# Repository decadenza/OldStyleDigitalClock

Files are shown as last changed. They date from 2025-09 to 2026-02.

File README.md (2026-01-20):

# Old Style Digital Clock
A simple, fully functional digital clock without microcontrollers.

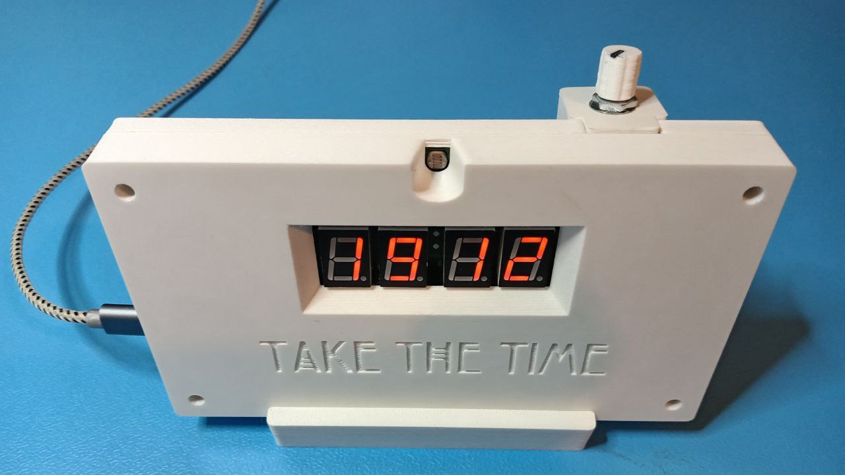
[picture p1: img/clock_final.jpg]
The old style digital clock


## Features
- HH:MM 24-hour format.
- Based on common and readily available components like counters and logic gates.
- This clock uses a Pierce oscillator circuit (quartz crystal), so it will keep the time much more accurately than a NE555 or similar timers.
- Powered by USB C female port.
- 2 x USB A ports for charging other devices (as dedicated charging ports - DCPs).
- Dimmable LEDs and self-adjusting brightness.

### LED brightness control
LEDs may result too faint in daylight and too bright at night. Therefore brightness is controlled by pulse-width modulation (PWM) and a potentiometer to adjust the duty cycle.
Furthermore, a light-dependent resistor (LDR) is introduced to automatically reduce the duty cycle at night.

The signal measured at one active LED segment is a square wave of a frequency > 30 Hz so that human eye cannot notice the flickering:

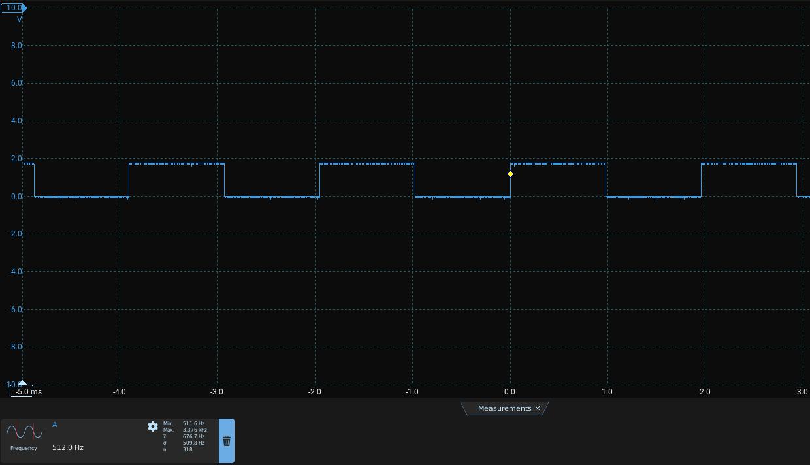
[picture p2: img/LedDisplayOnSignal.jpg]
LED signal


You may notice flickering if you use a camera to look at the clock. If this is a concern, you may reduce the C13 capacitor value to increase the frequency to the desired level. Full details in the schematics.

## PCB printing
A standard 2-layer PCB is used. You may generate the necessary Gerber and drill files using KiCad according to the specs of your supplier.

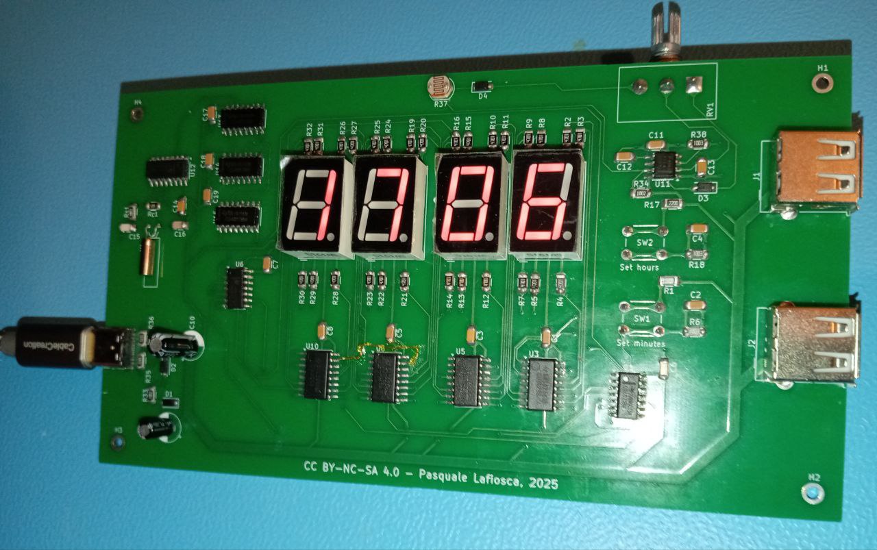
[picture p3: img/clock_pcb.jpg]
The old style digital clock


## 3D models
The clock may be completed by printing the case. See [3D printed parts](3DPrintedParts) folder. 

## License
This project is licensed under the **CC BY-NC-SA 4.0** license.  
© 2025 Pasquale Lafiosca

For more details, see the [LICENSE](LICENSE) file.

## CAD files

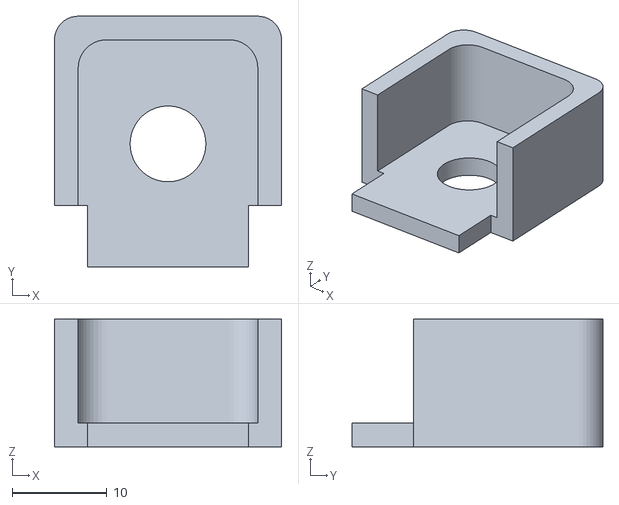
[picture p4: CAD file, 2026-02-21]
3DPrintedParts/potentiometer_shield.stl
24.0 x 26.5 x 13.5

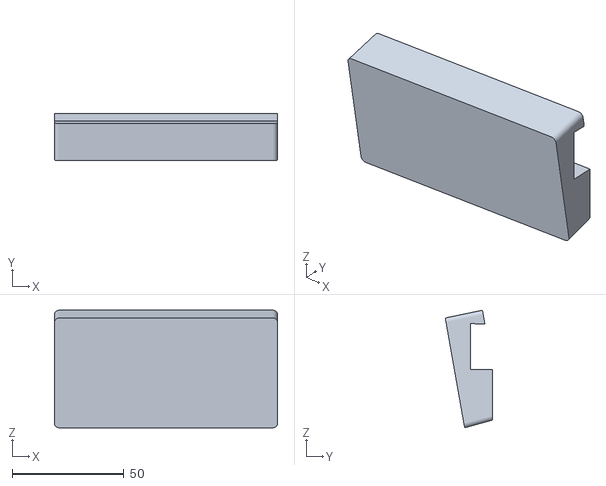
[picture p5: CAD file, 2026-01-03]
3DPrintedParts/support.stl
100.0 x 21.3 x 52.7

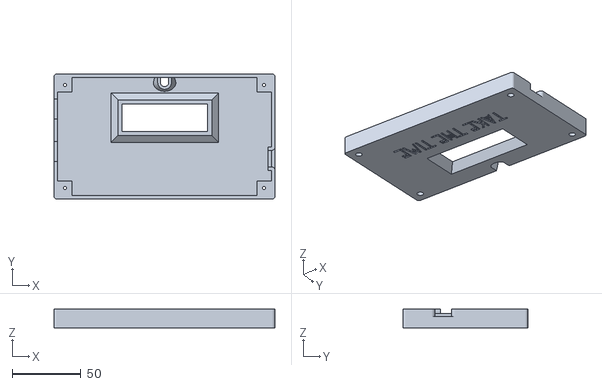
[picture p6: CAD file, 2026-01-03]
3DPrintedParts/front.stl
161.0 x 91.0 x 13.8

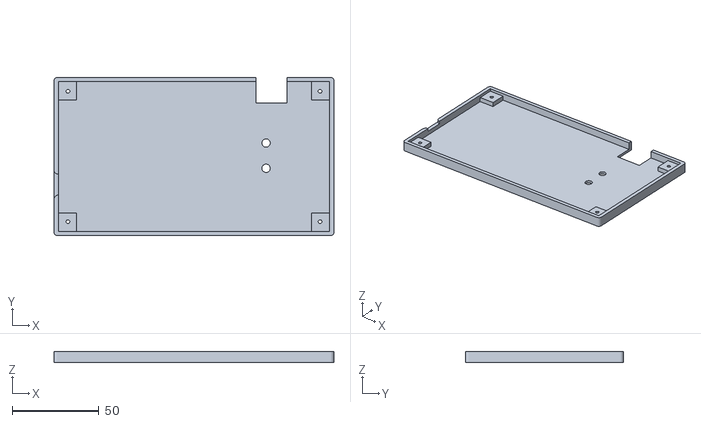
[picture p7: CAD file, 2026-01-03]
3DPrintedParts/back.stl
161.0 x 91.0 x 6.40

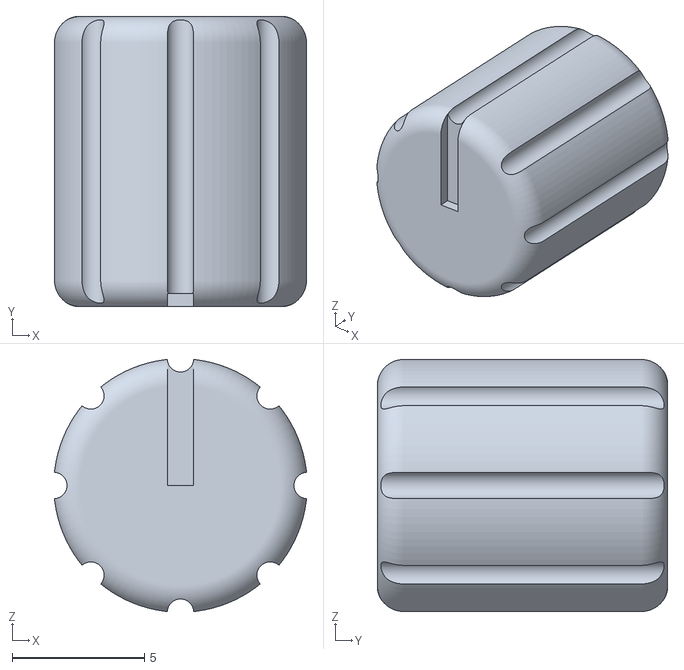
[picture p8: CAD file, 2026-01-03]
3DPrintedParts/potentiometer_cap.stl
9.54 x 11.0 x 9.54

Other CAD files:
3DPrintedParts/enclosure.blend

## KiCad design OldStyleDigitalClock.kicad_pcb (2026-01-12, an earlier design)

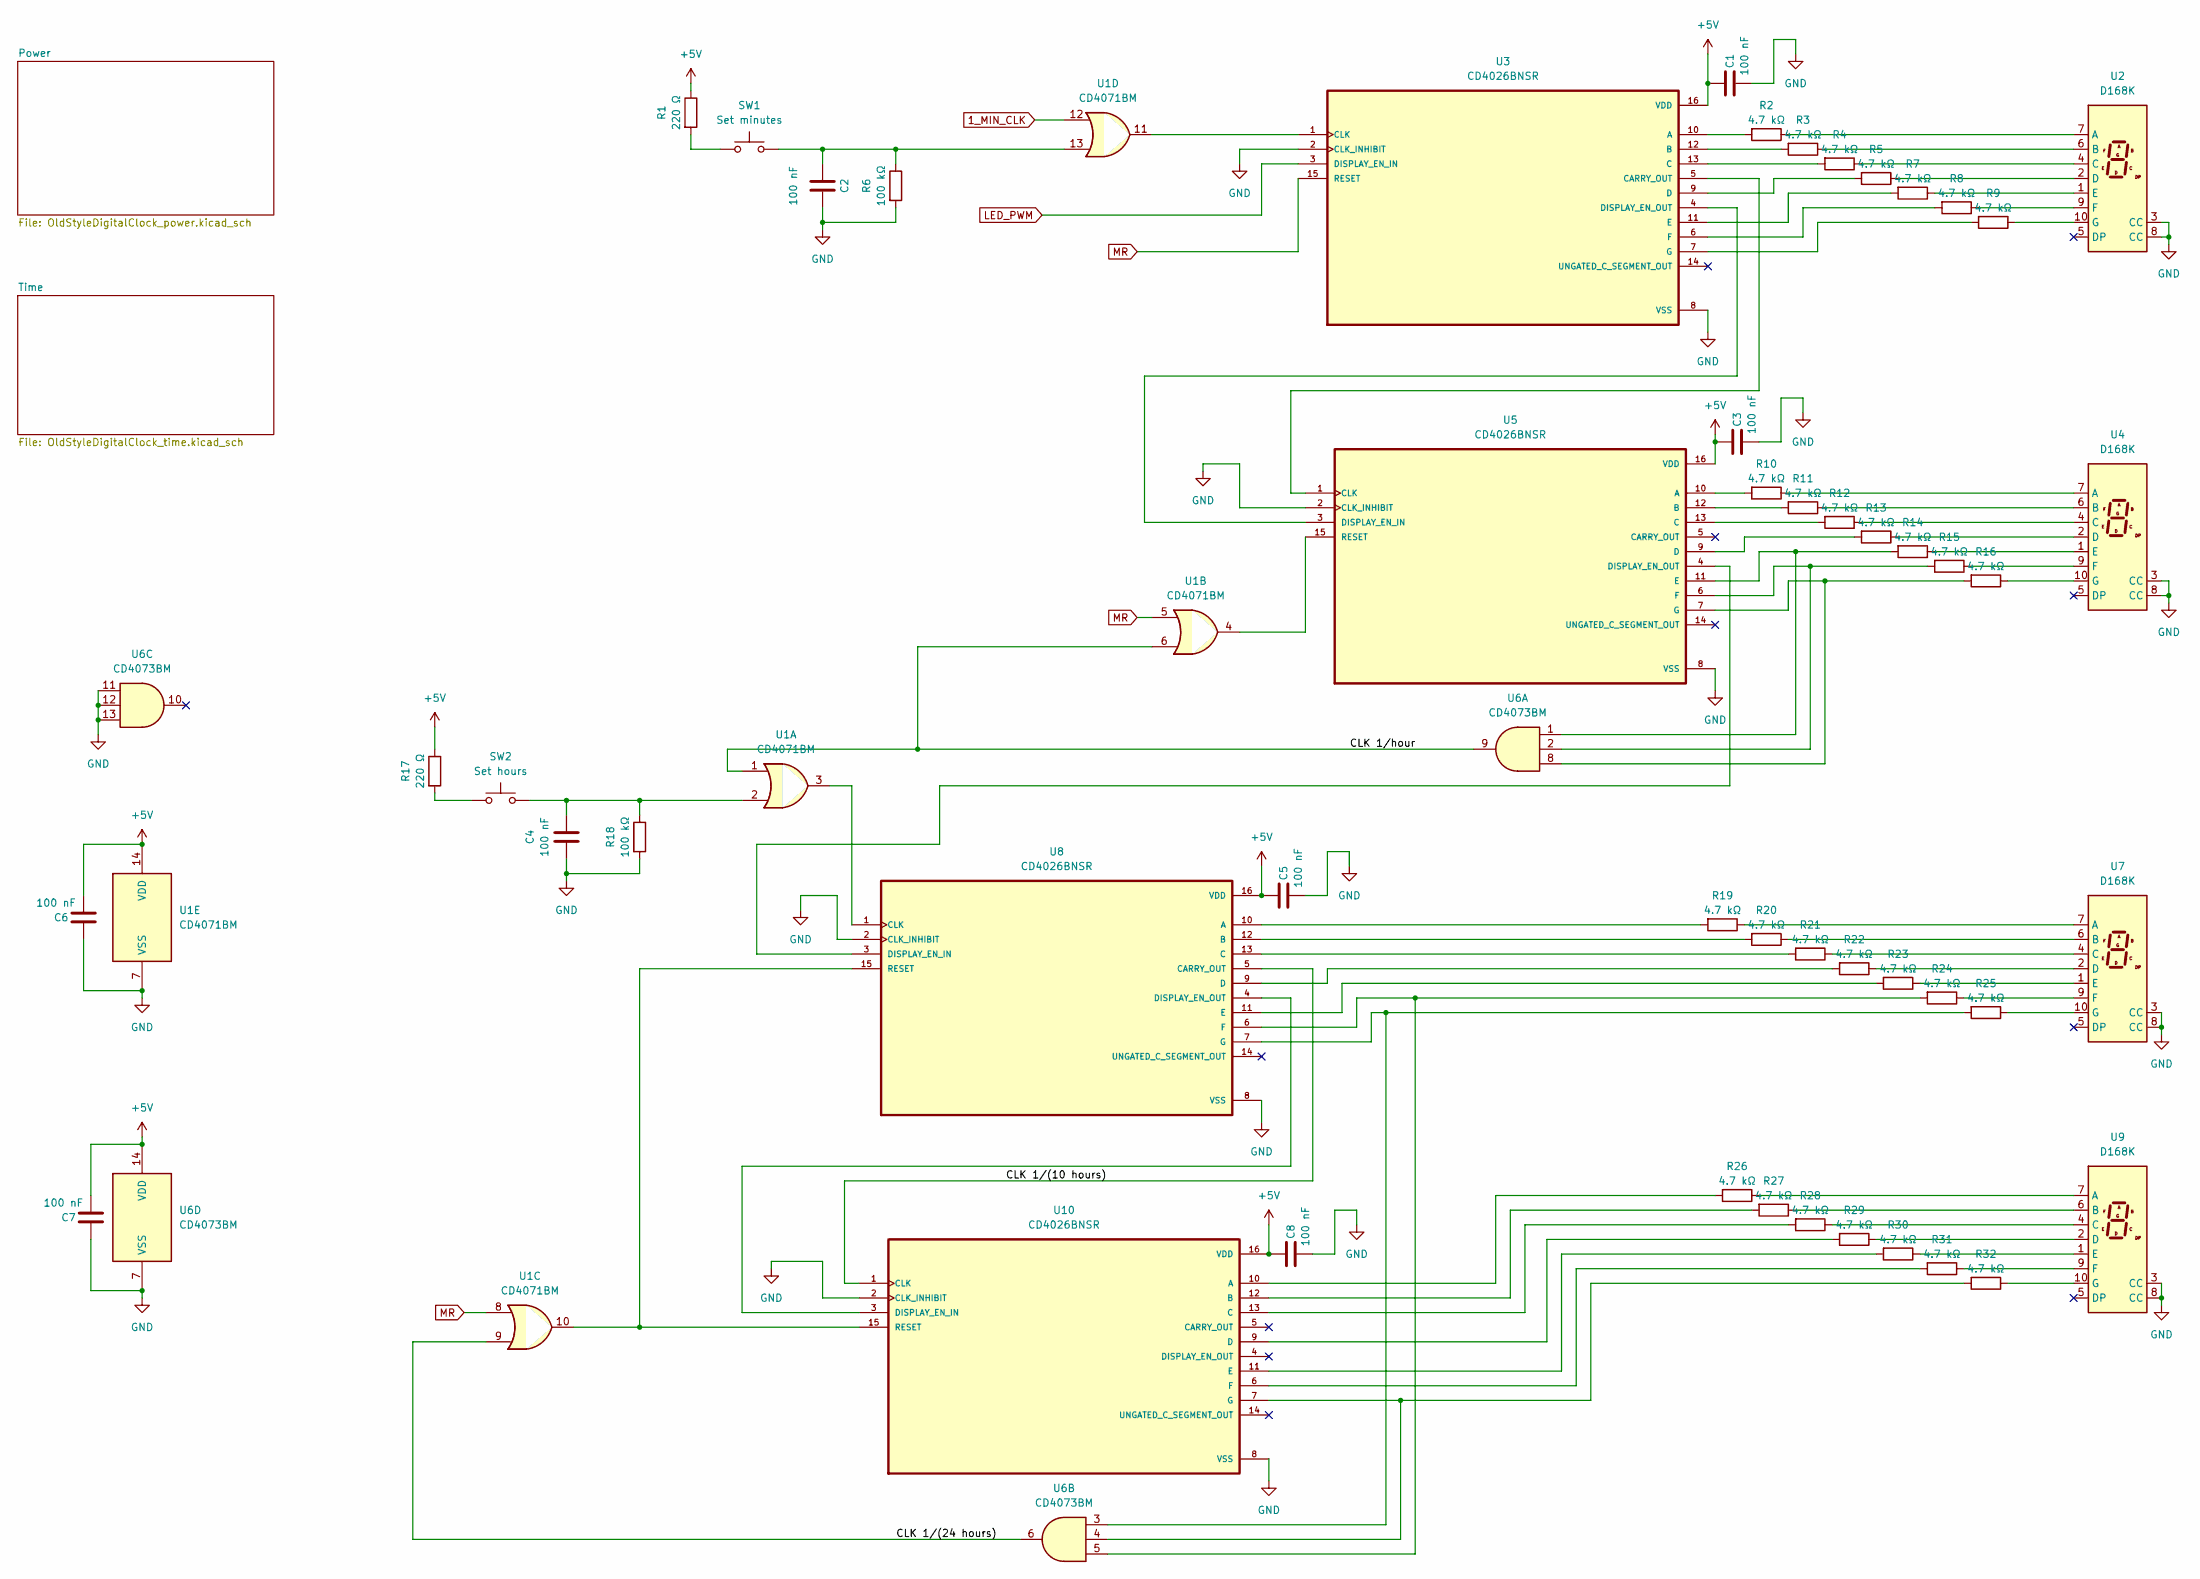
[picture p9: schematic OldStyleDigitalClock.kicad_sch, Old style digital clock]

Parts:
C1, C2, C3, C4, C5, C6, C7, C8: 100 nF; C_1206_3216Metric
R1, R17: 220 Ω; R_1206_3216Metric
R2, R3, R4, R5, R7, R8, R9, R10, R11, R12, R13, R14, R15, R16, R19, R20, R21, R22, R23, R24, R25, R26, R27, R28, R29, R30, R31, R32: 4.7 kΩ; R_1206_3216Metric
R6, R18: 100 kΩ; R_1206_3216Metric
SW1: Set minutes; SW_PUSH_6mm
SW2: Set hours; SW_PUSH_6mm
U1: CD4071BM; SOIC-14_3.9x8.7mm_P1.27mm
U2, U4, U7, U9: D168K; D1X8K
U3, U5, U8, U10: CD4026BNSR; SOIC-16W_5.3x10.2mm_P1.27mm
U6: CD4073BM; SOIC-14_3.9x8.7mm_P1.27mm

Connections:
1_MIN_CLK: U1.12; also elsewhere on the board
+5V: C1.1, C3.1, C5.1, C6.2, C7.2, C8.1, R1.1, R17.1, U1.14 (VDD), U3.16 (VDD), U5.16 (VDD), U6.14 (VDD), U8.16 (VDD), U10.16 (VDD); also elsewhere on the board
/CLK 1/(10 hours): U8.5 (CARRY_OUT), U10.1 (CLK)
/CLK 1/(24 hours): U1.9, U6.6
/CLK 1/hour: U1.1, U1.6, U6.9
GND: C1.2, C2.1, C3.2, C4.1, C5.2, C6.1, C7.1, C8.2, R6.2, R18.2, U1.7 (VSS), U2.3 (CC), U2.8 (CC), U3.2 (CLK_INHIBIT), U3.8 (VSS), U4.3 (CC), U4.8 (CC), U5.2 (CLK_INHIBIT), U5.8 (VSS), U6.7 (VSS), U6.11, U6.12, U6.13, U7.3 (CC), U7.8 (CC), U8.2 (CLK_INHIBIT), U8.8 (VSS), U9.3 (CC), U9.8 (CC), U10.2 (CLK_INHIBIT), U10.8 (VSS); also elsewhere on the board
LED_PWM: U3.3 (DISPLAY_EN_IN); also elsewhere on the board
MR: U1.5, U1.8, U3.15 (RESET); also elsewhere on the board
unnamed: C2.2, R6.1, SW1.2, U1.13
unnamed: C4.2, R18.1, SW2.2, U1.2
unnamed: R1.2, SW1.1
unnamed: R17.2, SW2.1
unnamed: R2.1, U2.7 (A)
unnamed: R3.1, U2.6 (B)
unnamed: R4.1, U2.4 (C)
unnamed: R5.1, U2.2 (D)
unnamed: R7.1, U2.1 (E)
unnamed: R8.1, U2.9 (F)
unnamed: R9.1, U2.10 (G)
unnamed: R2.2, U3.10 (A)
unnamed: R3.2, U3.12 (B)
unnamed: R4.2, U3.13 (C)
unnamed: U3.5 (CARRY_OUT), U5.1 (CLK)
unnamed: U1.11, U3.1 (CLK)
unnamed: R5.2, U3.9 (D)
unnamed: U3.4 (DISPLAY_EN_OUT), U5.3 (DISPLAY_EN_IN)
unnamed: R7.2, U3.11 (E)
unnamed: R8.2, U3.6 (F)
unnamed: R9.2, U3.7 (G)
unnamed: R10.1, U4.7 (A)
unnamed: R11.1, U4.6 (B)
unnamed: R12.1, U4.4 (C)
unnamed: R13.1, U4.2 (D)
unnamed: R14.1, U4.1 (E)
unnamed: R15.1, U4.9 (F)
unnamed: R16.1, U4.10 (G)
unnamed: R10.2, U5.10 (A)
unnamed: R11.2, U5.12 (B)
unnamed: R12.2, U5.13 (C)
unnamed: R13.2, U5.9 (D)
unnamed: U5.4 (DISPLAY_EN_OUT), U8.3 (DISPLAY_EN_IN)
unnamed: R14.2, U5.11 (E), U6.1
unnamed: R15.2, U5.6 (F), U6.2
unnamed: R16.2, U5.7 (G), U6.8
unnamed: U1.4, U5.15 (RESET)
unnamed: R19.1, U7.7 (A)
unnamed: R20.1, U7.6 (B)
unnamed: R21.1, U7.4 (C)
unnamed: R22.1, U7.2 (D)
unnamed: R23.1, U7.1 (E)
unnamed: R24.1, U7.9 (F)
unnamed: R25.1, U7.10 (G)
unnamed: R19.2, U8.10 (A)
unnamed: R20.2, U8.12 (B)
unnamed: R21.2, U8.13 (C)
unnamed: U1.3, U8.1 (CLK)
unnamed: R22.2, U8.9 (D)
unnamed: R23.2, U8.11 (E)
unnamed: R24.2, U6.5, U8.6 (F)
unnamed: R25.2, U6.3, U8.7 (G)
unnamed: R26.1, U9.7 (A)
unnamed: R27.1, U9.6 (B)
unnamed: R28.1, U9.4 (C)
unnamed: R29.1, U9.2 (D)
unnamed: R30.1, U9.1 (E)
unnamed: R31.1, U9.9 (F)
unnamed: R32.1, U9.10 (G)
unnamed: R26.2, U10.10 (A)
unnamed: R27.2, U10.12 (B)
unnamed: R28.2, U10.13 (C)
unnamed: R29.2, U10.9 (D)
unnamed: U8.4 (DISPLAY_EN_OUT), U10.3 (DISPLAY_EN_IN)
unnamed: R30.2, U10.11 (E)
unnamed: R31.2, U10.6 (F)
unnamed: R32.2, U6.4, U10.7 (G)
unnamed: U1.10, U8.15 (RESET), U10.15 (RESET)

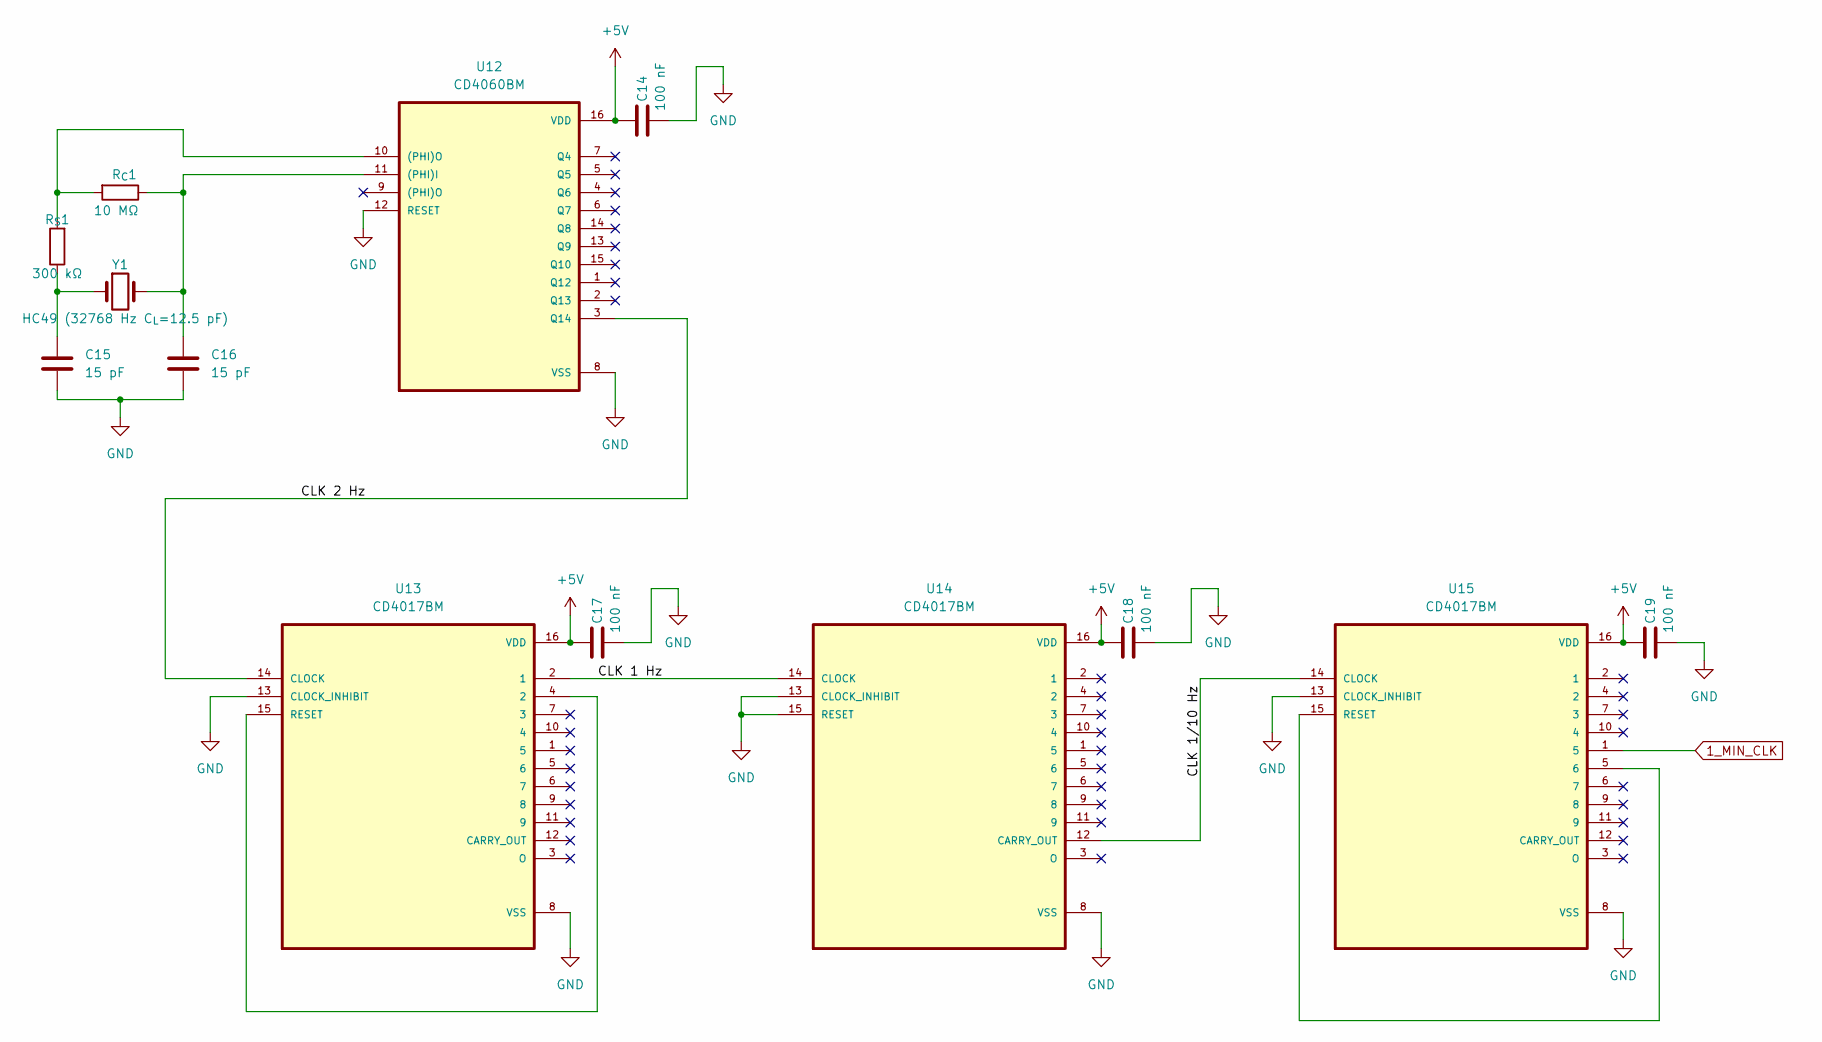
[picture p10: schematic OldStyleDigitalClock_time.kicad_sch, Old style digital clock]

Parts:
C14, C17, C18, C19: 100 nF; C_1206_3216Metric
C15, C16: 15 pF; C_1206_3216Metric
R_{C}1: 10 MΩ; R_1206_3216Metric
R_{S}1: 300 kΩ; R_1206_3216Metric
U12: CD4060BM; SOIC-16_3.9x9.9mm_P1.27mm
U13, U14, U15: CD4017BM; SOIC-16_3.9x9.9mm_P1.27mm
Y1: HC49 (32768 Hz C_{L}=12.5 pF); Crystal_AT310_D3.0mm_L10.0mm_Horizontal

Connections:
1_MIN_CLK: U15.1 (5); also elsewhere on the board
+5V: C14.1, C17.1, C18.1, C19.1, U12.16 (VDD), U13.16 (VDD), U14.16 (VDD), U15.16 (VDD); also elsewhere on the board
/Time/CLK 1 Hz: U13.2 (1), U14.14 (CLOCK)
/Time/CLK 1/10 Hz: U14.12 (CARRY_OUT), U15.14 (CLOCK)
/Time/CLK 2 Hz: U12.3 (Q14), U13.14 (CLOCK)
GND: C14.2, C15.2, C16.2, C17.2, C18.2, C19.2, U12.8 (VSS), U12.12 (RESET), U13.8 (VSS), U13.13 (CLOCK_INHIBIT), U14.8 (VSS), U14.13 (CLOCK_INHIBIT), U14.15 (RESET), U15.8 (VSS), U15.13 (CLOCK_INHIBIT); also elsewhere on the board
unnamed: C15.1, R_{S}1.1, Y1.1
unnamed: R_{C}1.2, R_{S}1.2, U12.10 ((PHI)O)
unnamed: C16.1, R_{C}1.1, U12.11 ((PHI)I), Y1.2
unnamed: U13.4 (2), U13.15 (RESET)
unnamed: U15.5 (6), U15.15 (RESET)

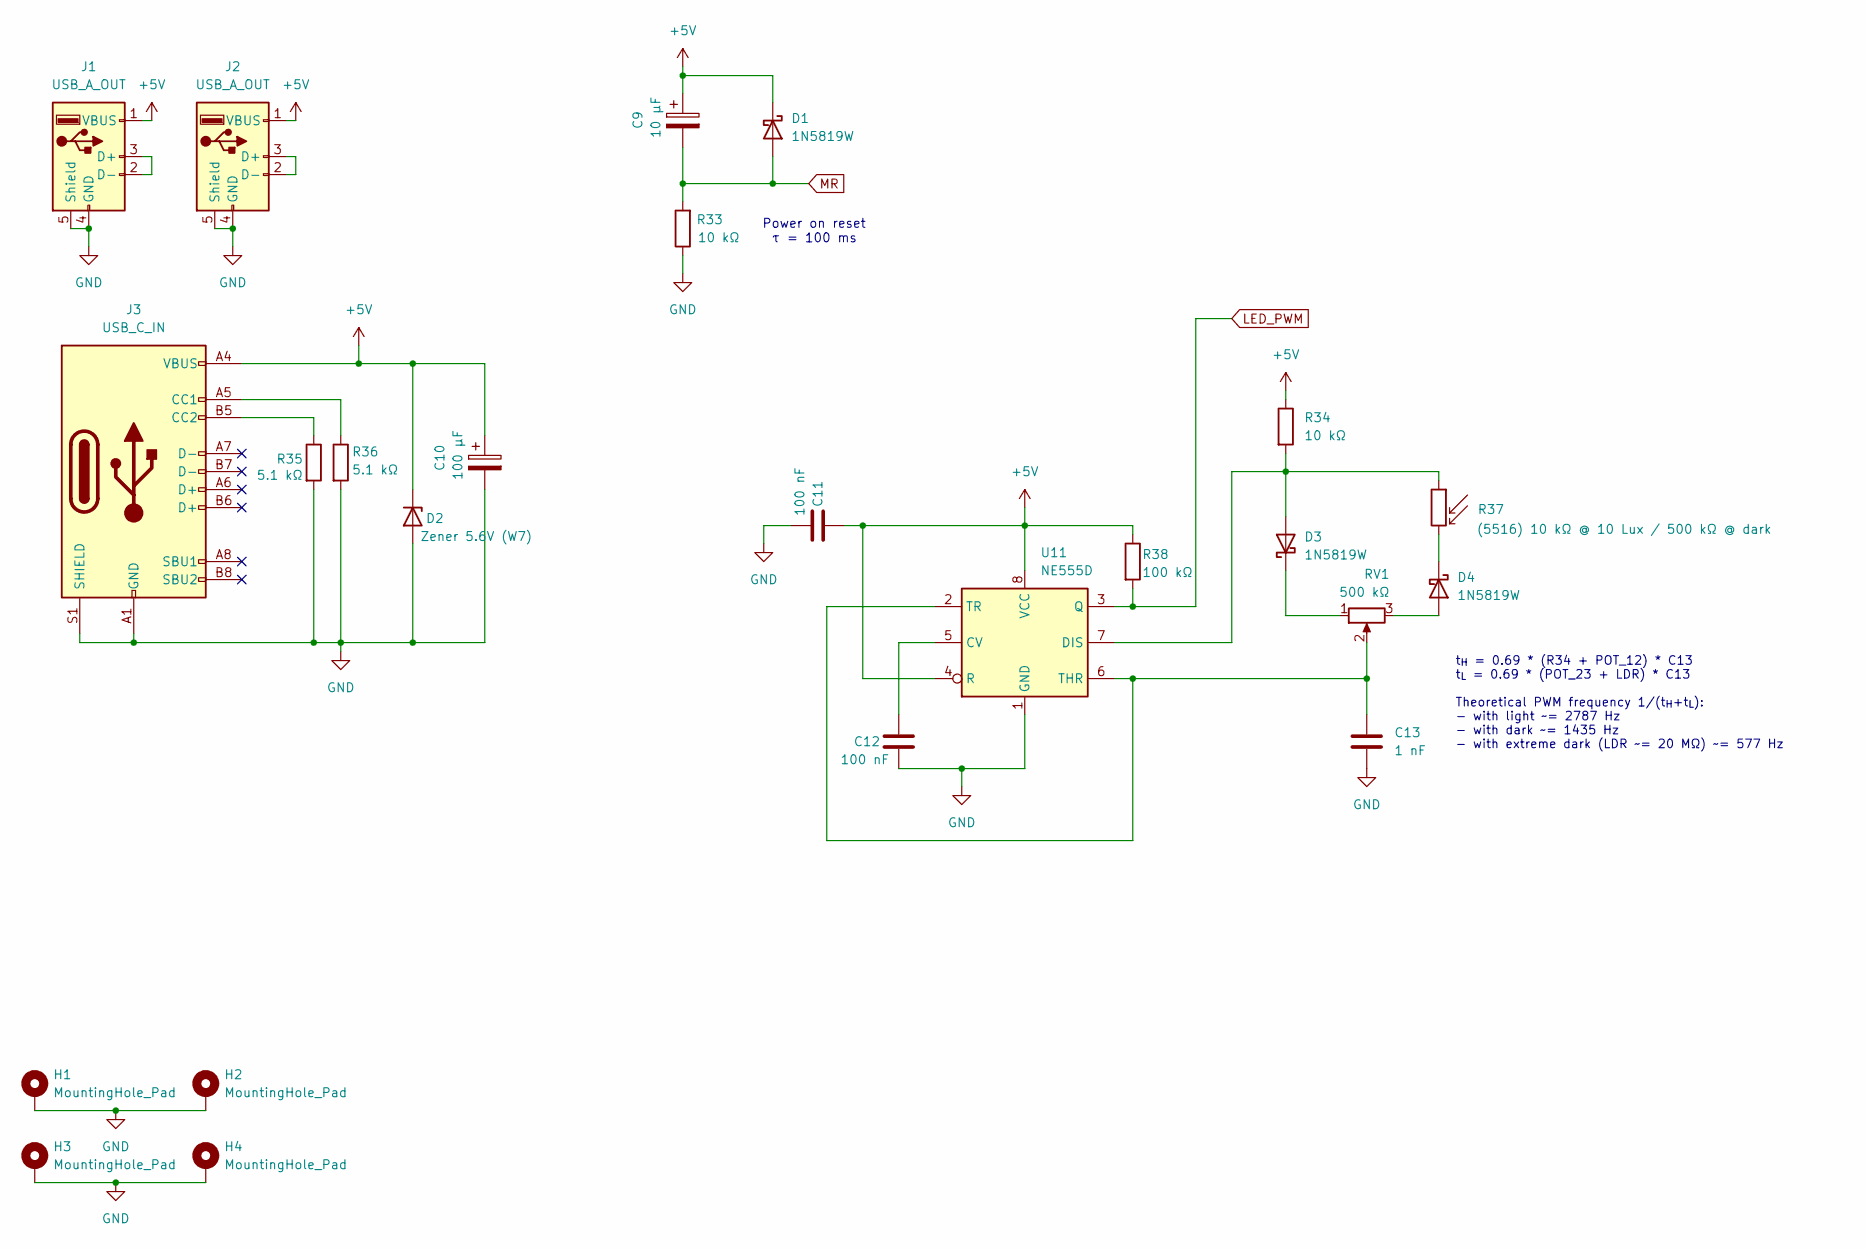
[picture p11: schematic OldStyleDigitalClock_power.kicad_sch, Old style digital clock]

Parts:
C9: 10 µF; CP_Radial_D6.3mm_P2.50mm
C10: 100 µF; CP_Radial_D6.3mm_P2.50mm
C11, C12: 100 nF; C_1206_3216Metric
C13: 1 nF; C_1206_3216Metric
D1, D3, D4: 1N5819W; D_SOD-123
D2: Zener 5.6V (W7); D_SOD-123
H1, H2, H3, H4: MountingHole_Pad; MountingHole_2.2mm_M2_DIN965_Pad
J1, J2: USB_A_OUT; USB_A_Molex_67643_Horizontal
J3: USB_C_IN; USB_C_Receptacle_XKB_U262-16XN-4BVC11
R33, R34: 10 kΩ; R_1206_3216Metric
R35, R36: 5.1 kΩ; R_1206_3216Metric
R37: (5516) 10 kΩ @ 10 Lux / 500 kΩ @ dark; R_LDR_5.1x4.3mm_P3.4mm_Vertical
R38: 100 kΩ; R_1206_3216Metric
RV1: 500 kΩ; Potentiometer_Alps_RK163_Single_Horizontal
U11: NE555D; SOIC-8_3.9x4.9mm_P1.27mm

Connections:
+5V: C9.1, C10.1, C11.1, D1.1 (K), D2.1 (K), J1.1 (VBUS), J2.1 (VBUS), J3.A4 (VBUS), J3.A9 (VBUS), J3.B4 (VBUS), J3.B9 (VBUS), R34.1, R38.1, U11.4 (R), U11.8 (VCC); also elsewhere on the board
GND: C10.2, C11.2, C12.2, C13.2, D2.2 (A), H1.1, H2.1, H3.1, H4.1, J1.4 (GND), J1.5 (Shield), J2.4 (GND), J2.5 (Shield), J3.A1 (GND), J3.A12 (GND), J3.B1 (GND), J3.B12 (GND), J3.S1 (SHIELD), R33.1, R35.2, R36.2, U11.1 (GND); also elsewhere on the board
LED_PWM: R38.2, U11.3 (Q); also elsewhere on the board
MR: C9.2, D1.2 (A), R33.2; also elsewhere on the board
unnamed: D3.2 (A), R34.2, R37.1, U11.7 (DIS)
unnamed: D3.1 (K), RV1.1
unnamed: D4.2 (A), RV1.3
unnamed: D4.1 (K), R37.2
unnamed: J1.2 (D-), J1.3 (D+)
unnamed: J2.2 (D-), J2.3 (D+)
unnamed: J3.A5 (CC1), R36.1
unnamed: J3.B5 (CC2), R35.1
unnamed: C12.1, U11.5 (CV)
unnamed: C13.1, RV1.2, U11.2 (TR), U11.6 (THR)

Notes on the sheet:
Power on reset τ = 100 ms
t_{H} = 0.69 * (R34 + POT_12) * C13 t_{L} = 0.69 * (POT_23 + LDR) * C13 Theoretical PWM frequency 1/(t_{H}+t_{L}): - with light ~= 2787 Hz - with dark ~= 1435 Hz - with extreme dark (LDR ~= 20 MΩ) ~= 577 Hz

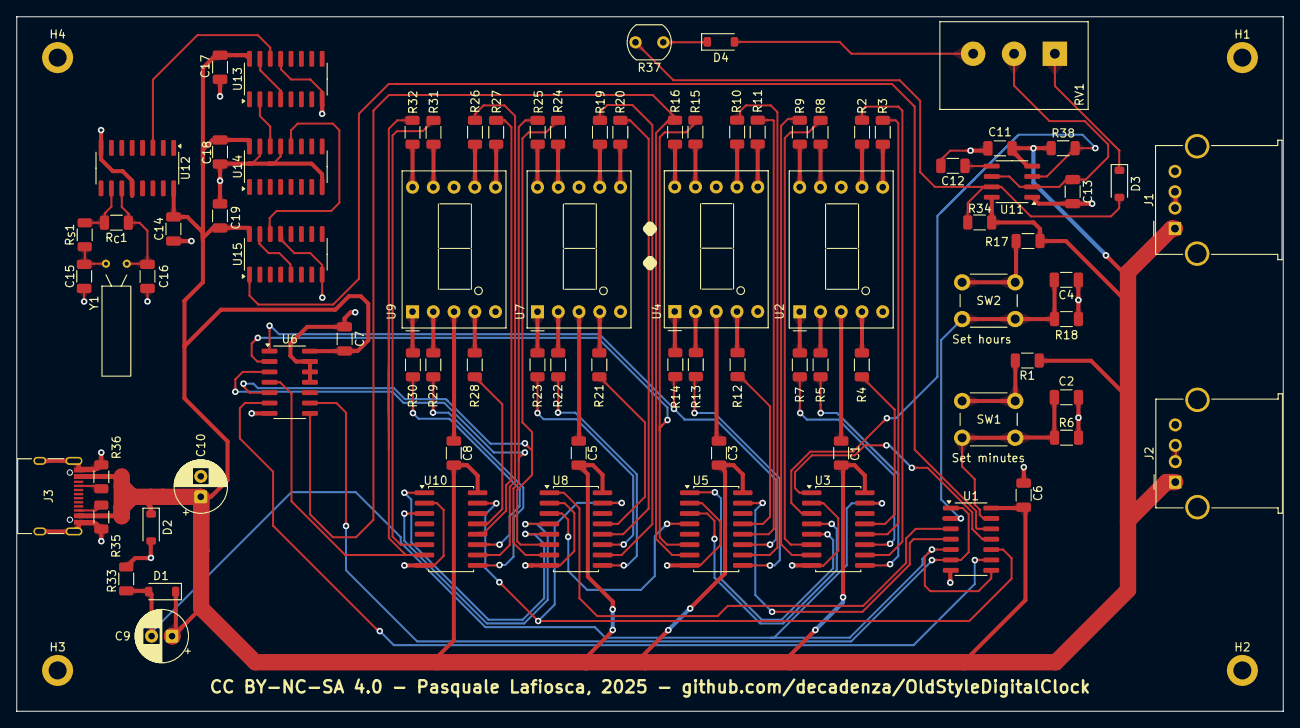
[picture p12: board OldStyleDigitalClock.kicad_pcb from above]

Board: 2 copper layers, 155.0 x 85.0 mm, 89 parts (0 on the bottom side), 94 nets.

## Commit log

2025-05-18 Uploaded project files
    [OldStyleDigitalClock.csv, OldStyleDigitalClock.kicad_pcb, OldStyleDigitalClock.kicad_sch]
2025-05-18 Added 3D printed stand and solar panel support
    [Solar panel support.stl, StandFlat.stl]
2025-05-18 Corrected 3D parts, added Blender file
    [OldStyleDigitalClockSupport.blend, Solar panel support.stl, Stand.stl]
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2025-05-31 Using 5 V solar cell instead of 4 V, as more appropriate for indoor situations
    [OldStyleDigitalClock.kicad_pcb, OldStyleDigitalClock.kicad_sch]
2025-08-17 Added different vertical and horizontal supports
    [OldStyleDigitalClockSupport.blend, Solar panel mount (horizontal).stl, Solar panel mount (vertical with support).stl]
2025-09-29 Using 512 Hz clock signal to rapidly turn on and off the LEDs via the CD4026 display enable pin, both saving 50% power and hopefully improving the battery charging. The LED attenuation is negligible.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
    [OldStyleDigitalClock.kicad_pcb, OldStyleDigitalClock.kicad_sch]
2025-09-30 Corrected LED display enable signal and decreased to 64 Hz to reduce capacitance and save power without any flickering visible
    [OldStyleDigitalClock.kicad_pcb, OldStyleDigitalClock.kicad_sch]
2025-10-11 Removed batteries and added USB connectors. One USB C for power in, two usb A power outlets. Pre-routing.
    [OldStyleDigitalClock.kicad_pcb, OldStyleDigitalClock.kicad_sch]
2025-10-12 Introducing PWM for dimmable LEDs
    [OldStyleDigitalClock.kicad_pcb, OldStyleDigitalClock.kicad_sch, OldStyleDigitalClock_main.kicad_sch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]
2025-10-13 Using standard astable multivibrator for LED dimming
    [OldStyleDigitalClock.kicad_sch, OldStyleDigitalClock_main.kicad_sch, OldStyleDigitalClock_power.kicad_sch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]
2025-10-13 Added photoresistor for automatic brightness adjustment
    [OldStyleDigitalClock_power.kicad_sch]
2025-10-16 Minor change to avoid issue with hours not changing
    [OldStyleDigitalClock.kicad_pcb, OldStyleDigitalClock.kicad_sch]
2025-10-17 Using OR gates instead of diodes. Changed POT for 555
    [OldStyleDigitalClock.kicad_sch, OldStyleDigitalClock_power.kicad_sch]
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2025-10-20 New PWM and POT configuration
    [OldStyleDigitalClock_power.kicad_sch]
2025-10-20 Added pull up on NA555 output. Minor changes.
    [OldStyleDigitalClock_power.kicad_sch]
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2025-10-20 Partial commit: Moved to SMD footprints
    [OldStyleDigitalClock.kicad_sch, OldStyleDigitalClock_power.kicad_sch, OldStyleDigitalClock_time.kicad_sch]
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2025-10-21 Constant frequency PWM with fixed LDR value
    [OldStyleDigitalClock_power.kicad_sch]
2025-10-21 Fixed typo
    [OldStyleDigitalClock_power.kicad_sch]
2025-10-22 Assigned footprints: first draft
    [OldStyleDigitalClock.kicad_pcb, OldStyleDigitalClock.kicad_sch, OldStyleDigitalClock_power.kicad_sch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]
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2025-10-28 Cleaning up for new layout
    [OldStyleDigitalClock.kicad_pcb]
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2025-11-02 Fixed issue in MR circuit. More tracks.
    [OldStyleDigitalClock.kicad_pcb, OldStyleDigitalClock_power.kicad_sch]
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2025-11-06 Tracks, first draft completed prior to design review
    [OldStyleDigitalClock.kicad_pcb, OldStyleDigitalClock_power.kicad_sch]
2025-11-06 connected mounting holes to GND
    [OldStyleDigitalClock.kicad_pcb, OldStyleDigitalClock_power.kicad_sch]
2025-11-06 Checked DRC, all ok except USB C clearances
    [OldStyleDigitalClock.kicad_pcb]
2025-11-07 Reduced board size, RDC passing except for USB C clearance.
    [OldStyleDigitalClock.kicad_pcb]
2025-11-07 Minor adjustments, moved oscillator away from mounting hole, improved some tracks.
    [OldStyleDigitalClock.kicad_pcb]
2025-11-08 Moved USB receptacles, minor changes. Marked no connect pins.
    [OldStyleDigitalClock.csv, OldStyleDigitalClock.kicad_pcb, OldStyleDigitalClock.kicad_sch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]
2025-11-08 Reviewed LED limiting resistors to stay within specs
    [OldStyleDigitalClock.kicad_pcb, OldStyleDigitalClock.kicad_sch, OldStyleDigitalClock_power.kicad_sch]
2025-11-09 Redesigned USB C input in a more compact way.
    [OldStyleDigitalClock.kicad_pcb, OldStyleDigitalClock_power.kicad_sch]
2025-11-13 Checked all IC against database and updated exact value and footprints
    [OldStyleDigitalClock.kicad_pcb, OldStyleDigitalClock.kicad_sch, OldStyleDigitalClock_time.kicad_sch]
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2025-11-25 fixed MR circuit (again)
    [OldStyleDigitalClock.kicad_pcb, OldStyleDigitalClock.kicad_sch, OldStyleDigitalClock_power.kicad_sch]
2025-11-25 Replaced rectifier diodes with Schottky ones
    [OldStyleDigitalClock_power.kicad_sch]
2025-11-25 Replaced diode values
    [OldStyleDigitalClock.kicad_pcb, OldStyleDigitalClock_power.kicad_sch]
2025-11-28 Cleaned up and built fabrication output with JLCPCB standards
    [OldStyleDigitalClock-B_Cu.gbr, OldStyleDigitalClock-B_Mask.gbr, OldStyleDigitalClock-B_Paste.gbr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]
2025-11-30 First 3D model file with PCB base.
    [OldStyleDigitalClock-B_Cu.gbr, OldStyleDigitalClock-B_Mask.gbr, OldStyleDigitalClock-B_Paste.gbr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]
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2025-11-30 Added LEd volume in 3D model
    [enclosure.blend]
2025-12-01 First front enclosure draft
    [enclosure.blend]
2025-12-01 Preparing for nutted slots
    [enclosure.blend]
2025-12-06 Enclosure with M3 nuts and adjusted thickness
    [enclosure.blend]
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2025-12-06 Enclosure with USB ports and buttons
    [enclosure.blend]
2025-12-06 Added LDR top hole
    [enclosure.blend]
2025-12-12 Adapted 3D parts to M2 bolts
    [enclosure.blend]
2025-12-12 Corrected Zener diode specs
    [OldStyleDigitalClock.kicad_sch, OldStyleDigitalClock_power.kicad_sch]
2025-12-14 Changed units for caps
    [OldStyleDigitalClock.kicad_pcb, OldStyleDigitalClock.kicad_sch, OldStyleDigitalClock_power.kicad_sch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]
2025-12-14 New layout for Pierce oscillator to reduce trace length and stray capacity
    [OldStyleDigitalClock.kicad_pcb]
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2025-12-17 Updated Pierce oscillator values with working values on PCB
    [OldStyleDigitalClock.kicad_pcb, OldStyleDigitalClock_time.kicad_sch]
2025-12-21 Reduced C13 value to avoid visible flickering
    [OldStyleDigitalClock.kicad_pcb, OldStyleDigitalClock_power.kicad_sch]
2025-12-21 Added missing reset connection for low digit of the hours
    [OldStyleDigitalClock.kicad_pcb, OldStyleDigitalClock.kicad_sch, OldStyleDigitalClock_power.kicad_sch]
2025-12-22 Added frontal hole for LDR
    [enclosure.blend]
2025-12-22 Added front hole for LDR with open top
    [enclosure.blend]
2025-12-22 Applied transformations, smoothing enclosure
    [enclosure.blend]
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2026-01-02 Restored old Rs value of 300k
    [OldStyleDigitalClock.kicad_pcb, OldStyleDigitalClock_time.kicad_sch]
2026-01-02 Front holes and taller front enclosure
    [enclosure.blend]
2026-01-02 Reduced front screw hole diameter
    [enclosure.blend]
2026-01-02 Replaced enclosure support to allow shorter M2 bolts, added extra gap for usb C connector
    [enclosure.blend]
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2026-01-03 Reduced C13 to 4.7 nF to account for stray capacitance and avoid flickering
    [OldStyleDigitalClock.kicad_pcb, OldStyleDigitalClock_power.kicad_sch]
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2026-01-04 Minor PCB layout change to reduce traces stray capacitance
    [OldStyleDigitalClock.kicad_pcb]
2026-01-05 Renamed folder, removed fabrication output
    [OldStyleDigitalClock-B_Cu.gbr, OldStyleDigitalClock-B_Mask.gbr, OldStyleDigitalClock-B_Paste.gbr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]
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2026-01-07 Updated PWm schematics calculations
    [OldStyleDigitalClock_power.kicad_sch]
2026-01-09 Reduced C13 further while staying within the 555 limit of 100 kHz even when LDR may raise to several MΩ. This avoids flickering.
    [OldStyleDigitalClock.kicad_pcb, OldStyleDigitalClock_power.kicad_sch]
2026-01-12 Added link in PCB description
    [OldStyleDigitalClock.kicad_pcb]
2026-02-21 Minor change to 3d pot shield
    [enclosure.blend, potentiometer_shield.stl]

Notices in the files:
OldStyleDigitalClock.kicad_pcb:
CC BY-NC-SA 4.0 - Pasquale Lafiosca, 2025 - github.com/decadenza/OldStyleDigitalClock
